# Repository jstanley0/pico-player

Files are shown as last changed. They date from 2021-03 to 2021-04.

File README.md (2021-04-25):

# pico-player
Music player for Raspberry Pi Pico and a pair of SN76489s

pico-player in action

## Installation
 * Copy the contents of `firmware` (`sound.py` and `music_player.py` to your Pico), via `rshell cp firmware/* /pyboard` or pasting into Thonny, etc.
 
## Playing songs from the Pico's file system
 * On your computer, run `python3 util/convert_midi.py example.mid example.dat`
 * Copy the output to the Pico via e.g. `rshell cp example.dat /pyboard`. It is a binary file so pasting it via an IDE isn't going to work.
 * On the Pico, instantiate a MusicPlayer and play the song:
```
from music_player import MusicPlayer
mp = MusicPlayer()
mp.play_song('example.dat')
```
## Playing MIDI files from a connected computer
 * run `python3 util/convert_midi.py example.mid -` 

## How it works
 * A (very) short PIO program clocks both sound chips. This could also be done with PWM, but the fractional multiplier on the Pico's PIO controller gives us a lot of flexibility on what frequency to clock the chips at, and since the chip has only a 10-bit frequency register, there are tradeoffs between clock rate and usable note range.
 * Another short PIO program sends data to both chips. It just tosses 10 bits at the first ten GPIOs, where the first eight go to both chips' data lines, and the last two go to each chip's Write Enable line. By setting exactly one of those bits, I control which sound chip latches the value. The PIO program then waits the requisite 32 cycles for the SN76489 to complete the I/O, while the main Python program keeps running! It just tosses a value in the FIFO and forgets. It's magic.
 * A timer callback fires every 50ms and manages the sound envelope for each playing note, and also updates the brightness of each LED.
 * The LEDs are managed with PWM. The Pico has *sixteen* PWM channels and they work with *any* of the GPIOs. It's magic.
 
## The hard part
Getting music data into a usable format is tricky. I wrote a script (util/convert_midi.py) that translates note-on and note-off events into a simple binary format that the microcontroller program can parse and play. The primary challenge is that we have only six notes of polyphony to work with, so it works best with simple MIDI files. I suggest opening files in e.g. MuseScore beforehand to identify channels to prioritize (with -p) or exclude (with -x). If no arguments are given, convert_midi.py will prioritize channels in tracks named "melody" or "vocals".
 
## Bill of Materials
 * one Raspberry Pi Pico
 * two SN76489 sound chips
 * two 10uF electrolytic capacitors (the value isn't critical)
 * one stereo 3.5mm audio jack (CUI SJ1-3533NG)
 * (optionally) one dual-gang 10k potentiometer for volume control (Alps RK09L)
 
## Wiring (see KiCad schematic in hardware/pico-player-pcb)
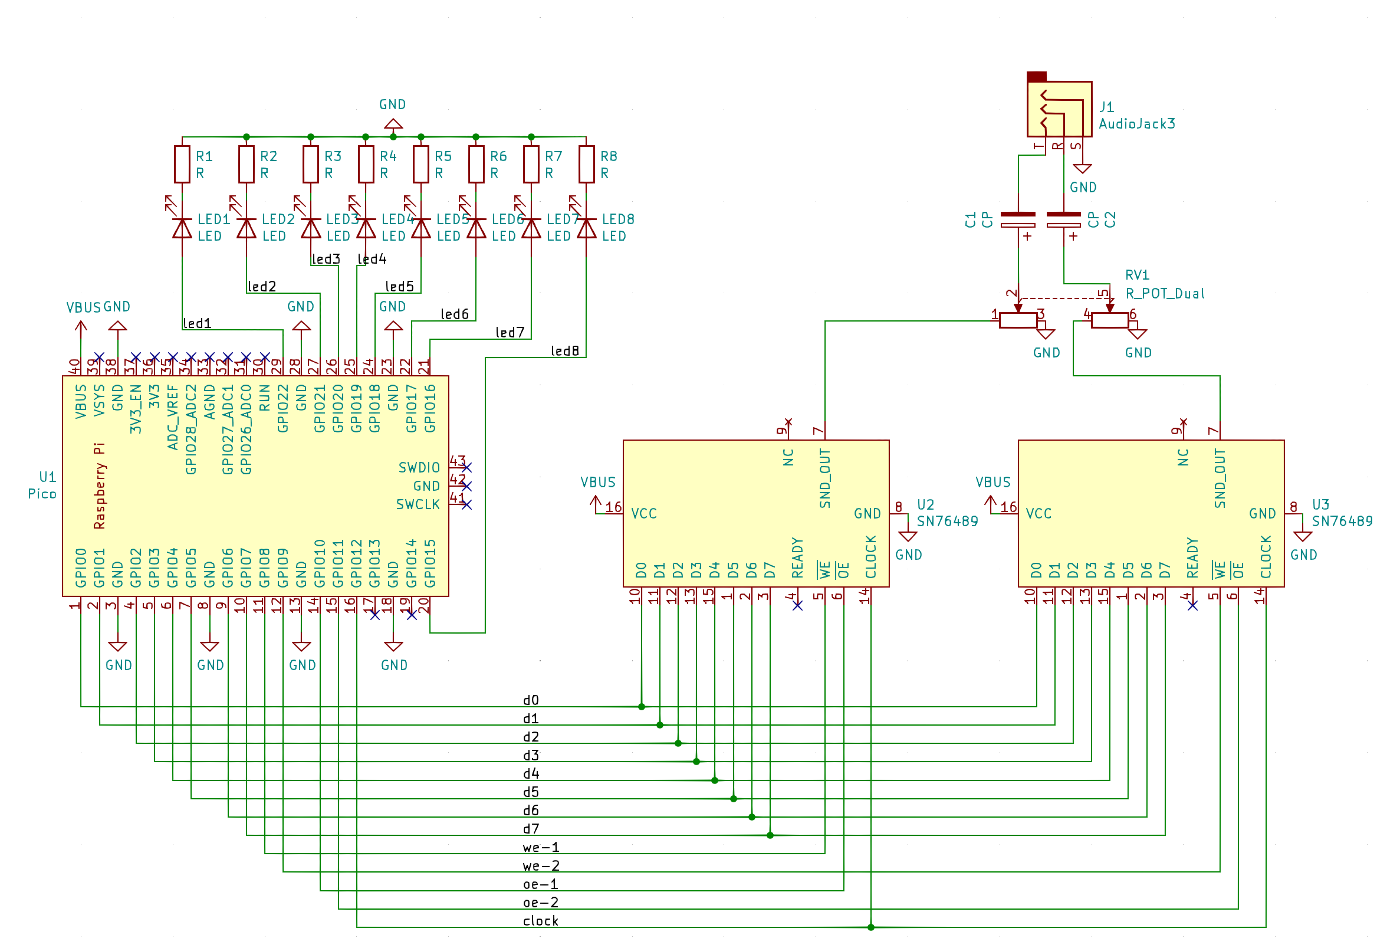
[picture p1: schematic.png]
pico-player schematic

 * VBUS to both chips' VCC (pin 16)
 * GND to both chips' GND (pin 8)
 * GPIOs 0..7 to the data lines of both sound chips in parallel (GPIO 0 to pin 10)
 * GPIO 8 to the left chip's /WE line (pin 5)
 * GPIO 9 to the right chip's /WE line
 * GPIO 10 to the left chip's /OE line (pin 6)
 * GPIO 11 to the right chip's /OE line
 * GPIO 12 to both chips' clock (pin 14)
 * Both sound chips' READY disconnected (it's 5V logic anyway)
 * GPIOs 15..22 to the blinkenlights!

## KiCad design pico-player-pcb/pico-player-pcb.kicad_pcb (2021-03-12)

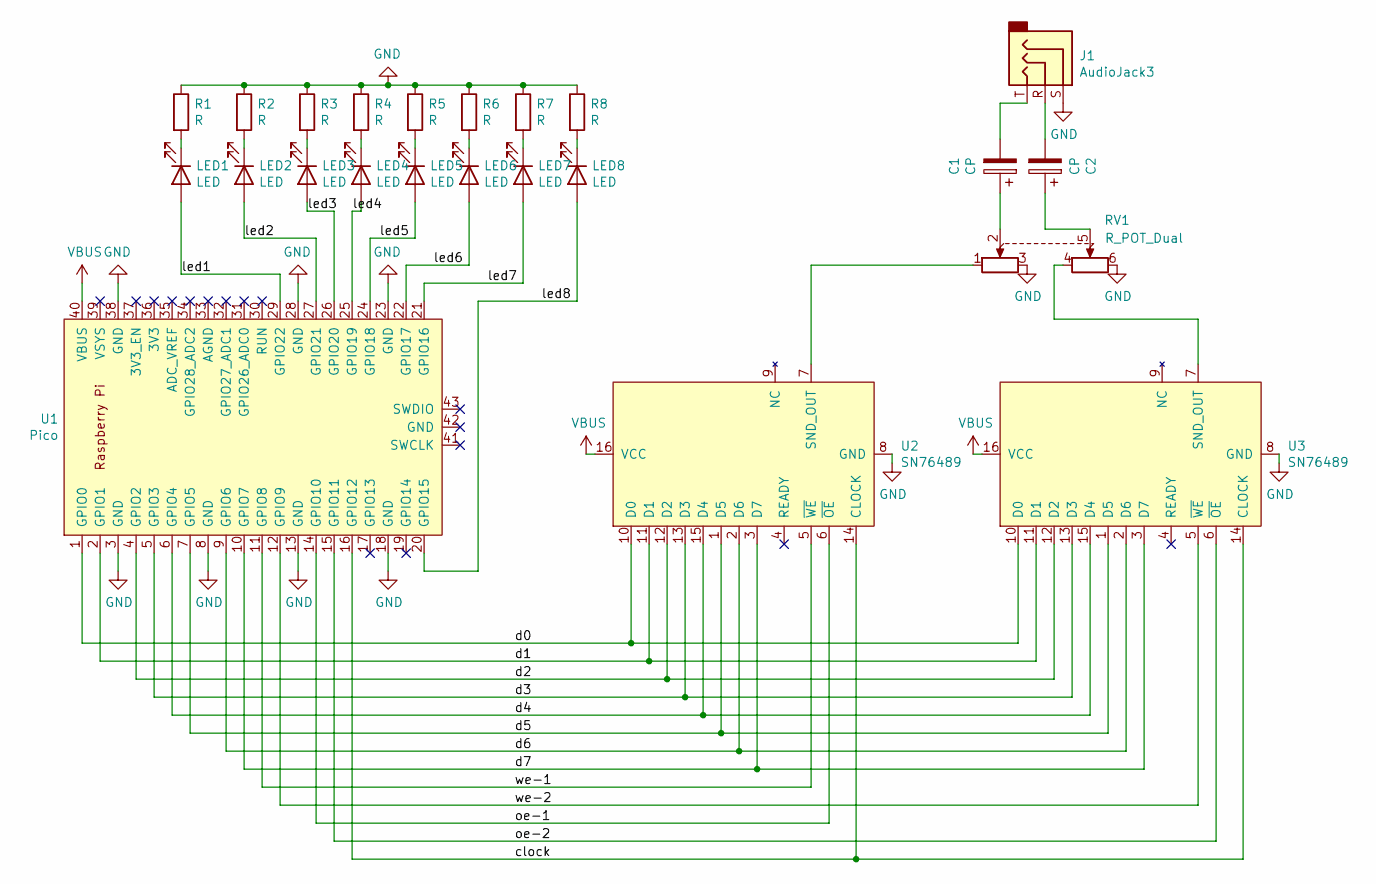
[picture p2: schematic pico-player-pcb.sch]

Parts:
C1, C2: CP; CP_Radial_D5.0mm_P2.50mm
J1: AudioJack3; Jack_3.5mm_CUI_SJ1-3533NG_Horizontal
LED1, LED2, LED3, LED4, LED5, LED6, LED7, LED8: LED; LED_D5.0mm_Clear
R1, R2, R3, R4, R5, R6, R7, R8: R; R_Axial_DIN0309_L9.0mm_D3.2mm_P2.54mm_Vertical
RV1: R_POT_Dual; Potentiometer_Alps_RK09L_Double_Vertical
U1: Pico; RPi_Pico_SMD_TH
U2, U3: SN76489; DIP-16_W7.62mm

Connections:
/clock: U1.16 (GPIO12), U2.14 (CLOCK), U3.14 (CLOCK)
/d0: U1.1 (GPIO0), U2.10 (D0), U3.10 (D0)
/d1: U1.2 (GPIO1), U2.11 (D1), U3.11 (D1)
/d2: U1.4 (GPIO2), U2.12 (D2), U3.12 (D2)
/d3: U1.5 (GPIO3), U2.13 (D3), U3.13 (D3)
/d4: U1.6 (GPIO4), U2.15 (D4), U3.15 (D4)
/d5: U1.7 (GPIO5), U2.1 (D5), U3.1 (D5)
/d6: U1.9 (GPIO6), U2.2 (D6), U3.2 (D6)
/d7: U1.10 (GPIO7), U2.3 (D7), U3.3 (D7)
/led1: LED1.2 (A), U1.29 (GPIO22)
/led2: LED2.2 (A), U1.27 (GPIO21)
/led3: LED3.2 (A), U1.26 (GPIO20)
/led4: LED4.2 (A), U1.25 (GPIO19)
/led5: LED5.2 (A), U1.24 (GPIO18)
/led6: LED6.2 (A), U1.22 (GPIO17)
/led7: LED7.2 (A), U1.21 (GPIO16)
/led8: LED8.2 (A), U1.20 (GPIO15)
/oe-1: U1.14 (GPIO10), U2.6 (~OE)
/oe-2: U1.15 (GPIO11), U3.6 (~OE)
/we-1: U1.11 (GPIO8), U2.5 (~WE)
/we-2: U1.12 (GPIO9), U3.5 (~WE)
GND: J1.S, R1.1, R2.1, R3.1, R4.1, R5.1, R6.1, R7.1, R8.1, RV1.3, RV1.6, U1.3 (GND), U1.8 (GND), U1.13 (GND), U1.18 (GND), U1.23 (GND), U1.28 (GND), U1.38 (GND), U2.8 (GND), U3.8 (GND)
unnamed: C1.1, RV1.2
unnamed: C1.2, J1.T
unnamed: C2.1, RV1.5
unnamed: C2.2, J1.R
unnamed: LED1.1 (K), R1.2
unnamed: LED2.1 (K), R2.2
unnamed: LED3.1 (K), R3.2
unnamed: LED4.1 (K), R4.2
unnamed: LED5.1 (K), R5.2
unnamed: LED6.1 (K), R6.2
unnamed: LED7.1 (K), R7.2
unnamed: LED8.1 (K), R8.2
unnamed: RV1.1, U2.7 (SND_OUT)
unnamed: RV1.4, U3.7 (SND_OUT)
VBUS: U1.40 (VBUS), U2.16 (VCC), U3.16 (VCC)

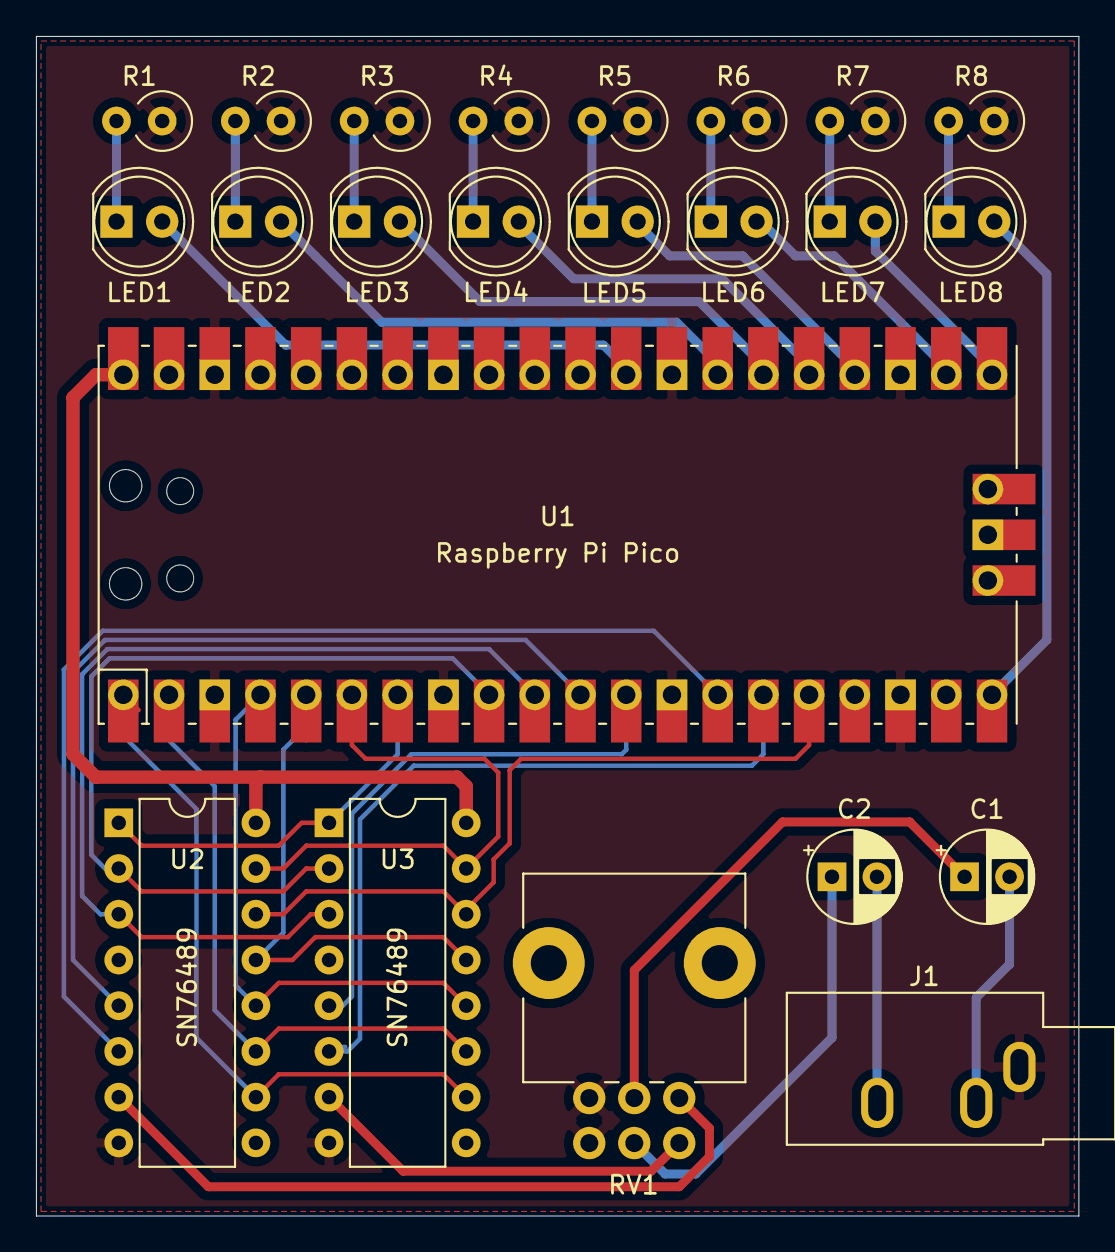
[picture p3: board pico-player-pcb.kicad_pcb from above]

Board: 2 copper layers, 57.9 x 65.5 mm, 23 parts (0 on the bottom side), 37 nets.

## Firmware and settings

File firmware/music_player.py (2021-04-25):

import utime
import math
from array import array
from machine import Pin, PWM, Timer
from sound import Sound

def read_words(filename):
    buffer = bytearray(128)
    with open(filename, 'rb', buffering=0) as file:
        while True:
            n = file.readinto(buffer)
            if n == 0:
                break
            i = 0
            while i + 1 < n:
                yield (buffer[i] << 8) | buffer[i + 1]
                i += 2

class MusicPlayer:
    LED_PINS = [16, 17, 18, 15, 19, 20, 21, 22]
    def __init__(self):
        self.sound = Sound()
        self._init_frequency_table()
        self.atten = [15] * 8
        self.target = [15] * 8
        self.decay_mask = [3] * 8
        self.decay_clock = 0
        self._init_leds()
        self.timer = Timer()

    def play_song(self, filename):
        try:
            self.start_playing()
            cmd_time = utime.ticks_ms()
            for word in read_words(filename):
                cmd_time = self.play_word(word, cmd_time)
            utime.sleep_ms(1000)
        finally:
            self.finish_playing()

    def play_words(self, words, cmd_time):
        try:
            for word in words:
                cmd_time = self.play_word(word, cmd_time)
            return cmd_time
        except KeyboardInterrupt:
            self.finish_playing()
            raise

    def play_word(self, word, cmd_time):
        cmd = (word >> 14) & 0x3
        if cmd == 0:
            # note on: V = voice; A = attenuation; N = note
            # 15 14 13 12 11 10  9  8  7  6  5  4  3  2  1  0
            #  0  0 V2 V1 V0 A3 A2 A1 A0 N6 N5 N4 N3 N2 N1 N0
            note = word & 0x7F
            attenuation = (word & 0x780) >> 7
            voice = (word & 0x3800) >> 11
            self._note_on(voice, note, attenuation)

        elif cmd == 1:
            # noise on: V = voice; A = attenuation; S = sustain; N = noise type
            # 15 14 13 12 11 10  9  8  7  6  5  4  3  2  1  0
            #  0  1  0  0  0 V0 S2 S1 S0 A3 A2 A1 A0 N2 N1 N0
            noise = (word & 0b111)
            atten = (word & 0b1111000) >> 3
            sustain = (word & 0b1110000000) >> 7
            voice = (word & 0b10000000000) >> 10
            voice = 3 + (voice * 4)
            self._noise_on(voice, noise, sustain, atten)

        elif cmd == 2:
            # delay: D = delay in milliseconds
            # 15 14 13 12 11 10  9  8  7  6  5  4  3  2  1  0
            #  1  0 DD DC DB DA D9 D8 D7 D6 D5 D4 D3 D2 D1 D0
            ms = word & 0x3FFF
            # TODO figure out why utime.sleep_ms() sometimes failed to wake up
            # and then be a bit nicer to the Pico by avoiding this busy wait
            cmd_time = utime.ticks_add(cmd_time, ms)
            while utime.ticks_diff(cmd_time, utime.ticks_ms()) > 0:
                pass

        else:
            # notes off: C = channel; V = voice mask
            # 15 14 13 12 11 10  9  8  7  6  5  4  3  2  1  0
            #  1  1  0  0  0  0  0  0 V7 V6 V5 V4 V3 V2 V1 V0
            mask = word & 0xFF
            self._notes_off(mask)

        return cmd_time

    def start_playing(self):
        self.timer.init(freq=80, mode=Timer.PERIODIC, callback=self._process_envelopes)

    def finish_playing(self):
        self.timer.deinit()
        self._lights_off()
        self.sound.silence()

    def _init_frequency_table(self):
        self.frequency_table = array('H') # unsigned short
        n = Sound.CLOCK_FREQ / (32 * 440)
        for midi_note in range(128):
            f = n / math.pow(2, (midi_note - 69.0) / 12)
            while f > 1023:
                f /= 2  # shift notes that won't fit into the frequency register up an octave until they do
            self.frequency_table.append(round(f))

    def _init_leds(self):
        self.pwms = []
        for pin in MusicPlayer.LED_PINS:
            if pin == None:
                self.pwms.append(None)
            else:
                pwm = PWM(Pin(pin))
                pwm.freq(120)
                pwm.duty_u16(0)
                self.pwms.append(pwm)

    def _lights_off(self):
        for pwm in self.pwms:
            if pwm:
                pwm.duty_u16(0)

    def _set_led_intensity(self, voice, atten):
        if self.pwms[voice]:
            duty = 0xfff0 >> atten
            self.pwms[voice].duty_u16(duty)

    def _note_on(self, voice, note, attenuation):
        self.atten[voice] = attenuation
        self.target[voice] = min(attenuation + 3, 15)
        self.sound.set_frequency(voice, self.frequency_table[note])
        self.sound.set_attenuation(voice, attenuation)
        self._set_led_intensity(voice, attenuation)

    def _noise_on(self, voice, noise, sustain, attenuation):
        self.atten[voice] = attenuation
        self.target[voice] = 15
        self.decay_mask[voice] = sustain
        self.sound.set_noise(voice, noise)
        self.sound.set_attenuation(voice, attenuation)
        self._set_led_intensity(voice, attenuation)

    def _notes_off(self, mask):
        for voice in range(8):
            if 0 != (mask & (1 << voice)):
                self.target[voice] = 15

    def _process_envelopes(self, _timer):
        self.decay_clock = (self.decay_clock + 1) & 7
        for voice in range(8):
            if (self.decay_mask[voice] & self.decay_clock) == 0:
                if self.atten[voice] < self.target[voice]:
                    self.atten[voice] += 1
                    self.sound.set_attenuation(voice, self.atten[voice])
                    self._set_led_intensity(voice, self.atten[voice])

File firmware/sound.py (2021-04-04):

# control a pair of TI SN76489 programmable sound generator ICs
# wiring: base pin on LSB (both chips in parallel)
#         base pin + 8 on left chip /WE
#         base pin + 9 on right chip /WE
#         base pin + 10 on left chip /OE
#         base pin + 11 on right chip /OE
#         both chips' READY disconnected

from rp2 import PIO, asm_pio, StateMachine
from machine import Pin

@asm_pio(set_init=PIO.OUT_LOW)
def _clock_prog():
    set(pins, 1)
    set(pins, 0)

@asm_pio(out_init=(PIO.OUT_LOW, PIO.OUT_LOW, PIO.OUT_LOW, PIO.OUT_LOW, PIO.OUT_LOW, PIO.OUT_LOW, PIO.OUT_LOW, PIO.OUT_LOW, PIO.OUT_HIGH, PIO.OUT_HIGH, PIO.OUT_LOW, PIO.OUT_LOW), out_shiftdir=PIO.SHIFT_RIGHT, set_init=(PIO.OUT_HIGH, PIO.OUT_HIGH))
def _xfer_prog():
    pull()
    out(pins, 10)[31]
    set(pins, 3)

class Sound:
    BASE_PIN = 0
    CLOCK_PIN = 12
    CLOCK_FREQ = 1_200_000
    LEFT = 0x200
    RIGHT = 0x100

    def __init__(self, base_pin = BASE_PIN, clock_pin = CLOCK_PIN, clock_freq = CLOCK_FREQ):
        self.base_pin = Pin(base_pin)
        self.we_pin = Pin(base_pin + 8)
        self.clock_pin = Pin(clock_pin)
        self.clock_freq = clock_freq

        self._init_clock()
        self._init_xfer()
        self.silence()

    def set_frequency(self, voice, freq):
        channel, voice = self._unpack_voice(voice)
        self._send_byte(channel, 0x80 | (voice << 5) | (freq & 0x0F))
        self._send_byte(channel, freq >> 4)

    def set_attenuation(self, voice, atten):
        channel, voice = self._unpack_voice(voice)
        self._send_byte(channel, 0x90 | (voice << 5) | atten)

    def set_noise(self, voice, noise):
        channel, voice = self._unpack_voice(voice)
        self._send_byte(channel, 0xE0 | noise)

    def silence(self):
        for voice in range(8):
            self.set_attenuation(voice, 15)

    def shutdown(self):
        self.silence()
        self._stop_xfer()
        self._stop_clock()

    def _unpack_voice(self, voice):
        if voice < 4:
            return (Sound.LEFT, voice)
        else:
            return (Sound.RIGHT, voice - 4)

    def _init_clock(self):
        self.clock_sm = StateMachine(0, _clock_prog, freq=self.clock_freq*2, set_base=self.clock_pin)
        self.clock_sm.active(1)

    def _stop_clock(self):
        self.clock_sm.active(0)

    def _init_xfer(self):
        self.xfer_sm = StateMachine(1, _xfer_prog, freq=self.clock_freq, out_base=self.base_pin, set_base=self.we_pin)
        self.xfer_sm.active(1)

    def _stop_xfer(self):
        self.xfer_sm.active(0)

    def _send_byte(self, channel, byte):
        self.xfer_sm.put(channel | byte)

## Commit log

2021-02-10 some code generation optimizations
    * temporally consolidate note-off and note-on events
    when separated by less than 10ms
    * skip unnecessary note-off events when starting a
    new note immediately in the voice
    * use a single 16-bit message to turn off an arbitrary set
    of voices instead of one 8-bit message per voice
    these changes reduce the demo file size by 50% and they make
    the code for the player that I haven't written yet simpler too.
    I should write that player. :P
    [convert_midi.py, sound.py]
2021-02-10 envelope handling and cleanup
    protip: ALWAYS deinit your timer in a finally block
2021-02-13 don't require a total order for priority
    simply have priority channels and excluded channels
    also don't have preferred voices; use the least-recently used
    voice on the channel's preferred chip instead, to maximize
    release time
    and tweak velocity/attenuation mapping again
2021-02-16 schematic and PCB (untested)
    [pico-player-pcb.kicad_pcb, pico-player-pcb.sch]
2021-02-16 minor pcb tweak
    [pico-player-pcb.kicad_pcb]
2021-02-16 protip: draw your traces and then don't look at them again
    [pico-player-pcb.kicad_pcb]
2021-02-19 I think probably the pot was wired backward
    [pico-player-pcb.kicad_pcb, pico-player-pcb.sch]
2021-02-26 ... sigh, it was better before
    [pico-player-pcb.kicad_pcb, pico-player-pcb.sch]
2021-02-27 adjust to match the PCB
2021-03-12 rearrange slightly
    the potentiometer was upside-down, at least when you install
    a knob with a marker
    it's nice to have the audio jack on the side, so you can
    stand the board up
    [pico-player-pcb.kicad_pcb, pico-player-pcb.sch]
2021-03-13 add noise channel LEDs
    (they're not actually used yet)
    [music_player.py]
2021-03-21 automatically prioritize channels in "melody" or "vocals" track
2021-04-06 hopefully "fix" the intermittent hanging problem
    occasionally utime.sleep_ms() failed to wake up. I suspect it
    involved some kind of a race condition involving the Timer
    because I never saw the problem occur with envelopes disabled
    but envelopes are required for percussion (and also the
    frequency of the callback has increased)
    this workaround seems okay so far
    [music_player.py]
2021-04-08 upload schematic as image
    for mere mortals who want to build this thing on a breadboard and definitely do not want to involve KiCad
2021-04-08 add schematic to readme
2021-04-25 add ability to stream a midi file directly to the pico
    pass - as the output file parameter to util/convert_midi.py,
    and it will connect to the Pico over USB and play music by
    sending small chunks of data over the REPL. no need to copy
    files to the Pico's file system anymore. (other than the
    actual music player, of course)
